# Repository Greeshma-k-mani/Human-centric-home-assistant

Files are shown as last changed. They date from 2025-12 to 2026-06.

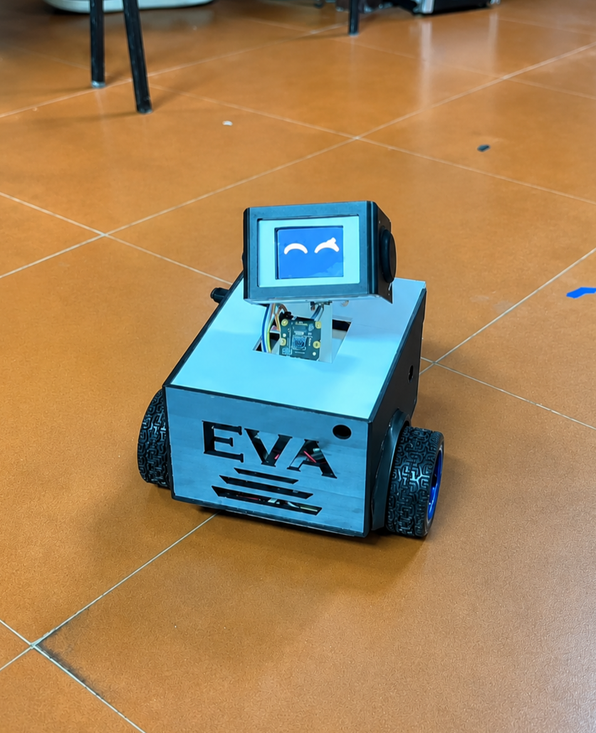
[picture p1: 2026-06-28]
HUMAN_CENTRIC_EMBODIED_HOME_ASSISTANT.png

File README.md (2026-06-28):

# EVA — Human Centered Embodied Home Assistant 🤖

> Voice-activated home assistant robot with face recognition, radar presence detection,
> expressive head movement, and smart home automation.
> 
> 🥇 **First Place — INNOVIX, RISE 2026 | FISAT ECE Department**

---

## 🧠 What is EVA?

EVA is a fully functional human-centric home assistant robot built on **Raspberry Pi 2 + ESP32**,
designed to recognize users, navigate to them, and assist through natural voice interaction.

Unlike conventional voice assistants, EVA physically moves to the user, verifies identity
through face recognition, and responds with expressive animations — making interaction
more natural and personal.

---

## ⚙️ System Architecture

```
┌─────────────────────────────────────────┐
│         RASPBERRY PI 2 MODEL B          │
│  Face Recognition · Voice · Navigation  │
│  Intent Engine · Flask Web UI · Groq AI │
└──────────────┬──────────────────────────┘
               │ HTTP (WiFi)
┌──────────────▼──────────────────────────┐
│              ESP32 WROOM-32             │
│  Motors · Servos · TFT · Radar · Face  │
└──────────────────────────────────────────┘
               │ HTTP (WiFi)
┌──────────────▼──────────────────────────┐
│            ESP8266 NodeMCU              │
│     Garden Relay · Light Control        │
└──────────────────────────────────────────┘
```

---

## 🔧 Features

| Feature | Details |
|---|---|
| 🎙️ Wake Word | Porcupine — "Hey Eva" |
| 👁️ Face Recognition | OpenCV — Haar + LBPH |
| 📡 Presence Detection | LD2410 mmWave Radar |
| 😊 Face Display | ST7735R TFT — 6 bitmap expressions |
| 🤖 3-DoF Head | MG90S servos — Yaw · Pitch · Roll |
| 🚗 Navigation | TB6612FNG + N25 gear motors |
| 🏠 Home Automation | ESP8266 relay — pump + lights |
| 🧠 AI Conversation | Groq LLM (Llama 3) |
| 🌐 Web UI | Flask dashboard — auth + controls |
| 🔌 Custom PCB | KiCad 9.0.5 — full system integration |
| 🖨️ Body | 3D printed enclosure (PLA) |

---

## 🛠️ Hardware

- Raspberry Pi 2 Model B
- ESP32 WROOM-32 DevKit
- ESP8266 NodeMCU
- Pi Camera Module V2 (NoIR)
- ST7735R TFT Display
- HLK-LD24 mmWave Radar
- TB6612FNG Motor Driver
- N25 Metal Gear Motors × 2
- MG90S Servo Motors × 3
- PAM8403 Audio Amplifier
- Custom PCB (KiCad 9.0.5)
- 2S Li-ion Battery (7.4V)

---

## 💻 Software Stack

```python
stack = {
    "Pi"      : ["Python 3", "OpenCV", "Porcupine", "Flask",
                 "edge-TTS", "Google STT", "Groq LLM"],
    "ESP32"   : ["Arduino C++", "WebServer", "SPI", "LEDC PWM"],
    "ESP8266" : ["Arduino C++", "ESP8266WebServer"],
    "PCB"     : ["KiCad 9.0.5"],
    "Body"    : ["Fusion 360", "3D Printing (PLA)"],
}
```

---

## 📬 Contact




---

GitHub: https://github.com/Greeshma-k-mani

LinkedIn: https://www.linkedin.com/in/greeshma-k-mani

<p align="center"><i>Built with curiosity. Powered by embedded silicon. Driven by the need to build things that actually work.</i></p>

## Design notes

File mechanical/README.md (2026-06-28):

## 3DOF Head Mechanical Design

This directory contains the mechanical design files for a 3DOF servo-driven head
used in the early development phase of the interactive home assistant robot.

Degrees of Freedom:
- Yaw (left / right)
- Pitch (up / down)
- Roll (tilt)

Design notes:
- Designed for MG90S micro servos
- Optimized for 3D printing (PLA)
- Intended for expressive motion, not load-bearing use

## File Structure
- Assembly files are located in this directory
- Render images are located in the `renders/` folder

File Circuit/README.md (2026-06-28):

# PCB Design — EVA Human Centered Embodied Home Assistant

Circuit schematic and PCB layout for the EVA project, designed using **KiCad 9.0.5**.

---

## 📋 System Overview

| Controller | Role |
|---|---|
| **Raspberry Pi 2 Model B** | Face recognition, voice interaction, navigation logic, Flask web UI |
| **ESP32 WROOM-32** | Motors, servos, TFT display, radar, HTTP server |
| **ESP8266 NodeMCU** | Garden relay control, WiFi automation |

---

## 🔌 Peripherals

| Component | Interface |
|---|---|
| ST7735R TFT Display | SPI |
| MG90S Servo × 3 (Yaw, Pitch, Roll) | PWM |
| TB6612FNG Motor Driver | PWM + GPIO |
| N25 Gear Motors × 2 | TB6612FNG |
| HLK-LD24 mmWave Radar | UART2 |
| 2-Channel Relay Module | GPIO (ESP8266) |
| PAM8403 Audio Amplifier | GPIO |

---

## ⚡ Power Architecture

- **Source:** 2S Li-ion Battery (7.4V)
- **MINI560:** 5V regulated — Raspberry Pi
- **Mini360:** 3.3V regulated — ESP32, ESP8266, logic
- **LM2590:** 6V regulated — Motors and servos
- **Protection:** 10A fuse + power switch
- **Decoupling:** Bulk and bypass capacitors on all power rails

---

## 📐 PCB Design Status

| Item | Status |
|---|---|
| Schematic | ✅ Completed |
| PCB Layout | ✅ Completed |
| 3D Render | ✅ Completed |
| Fabrication | ✅ Fabricated |
| Testing | ✅ Tested |
| Design Tool | KiCad 9.0.5 |

---

---

## 📝 Design Notes

- Common ground reference across all modules
- Decoupling capacitors placed close to all ICs
- High-current motor and servo rails isolated from logic rails
- Designed for low-voltage, non-safety-critical academic use

---

> This PCB is part of an academic embedded systems project and is not intended for commercial or safety-critical applications.

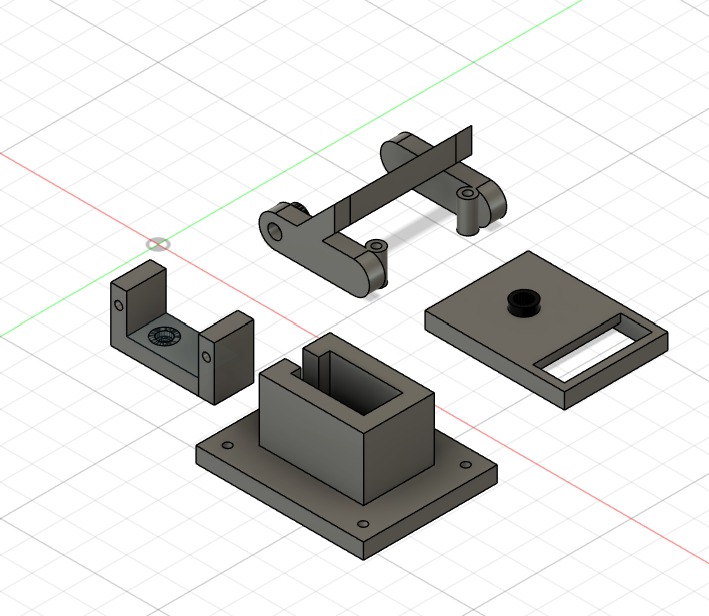
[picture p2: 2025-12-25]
mechanical/renders/exploded view.jpeg

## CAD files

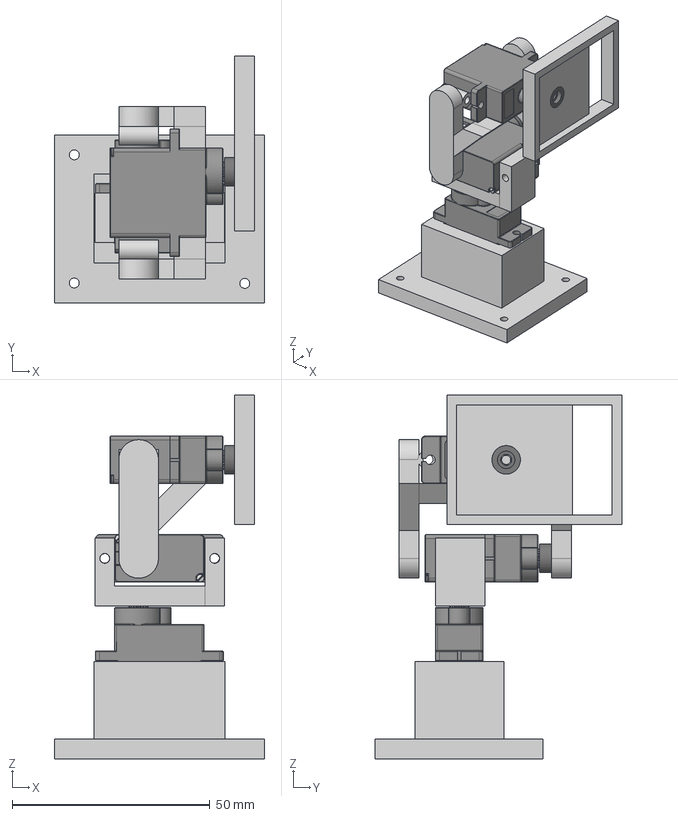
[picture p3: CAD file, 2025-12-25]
mechanical/assembly/head_assembly_v1.step
53.1 x 62.3 x 92.0 mm
Shaft x 3
Horn x 3
Screw x 3

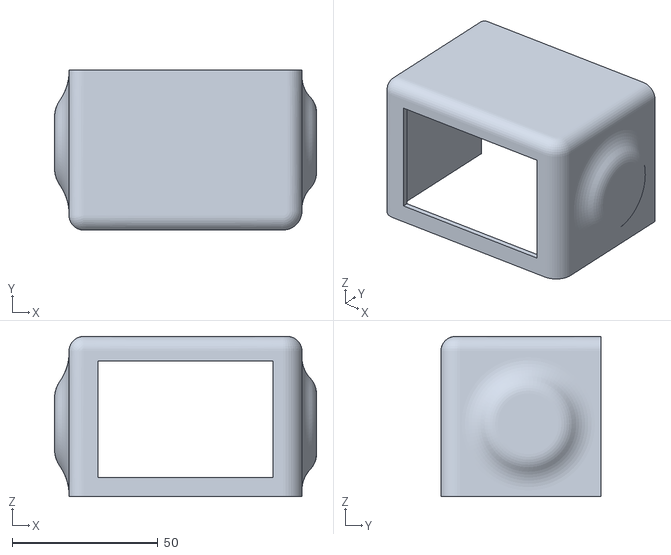
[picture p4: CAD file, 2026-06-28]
mechanical/parts/EVA_HEAD_COVER.stl
90.0 x 55.0 x 55.0

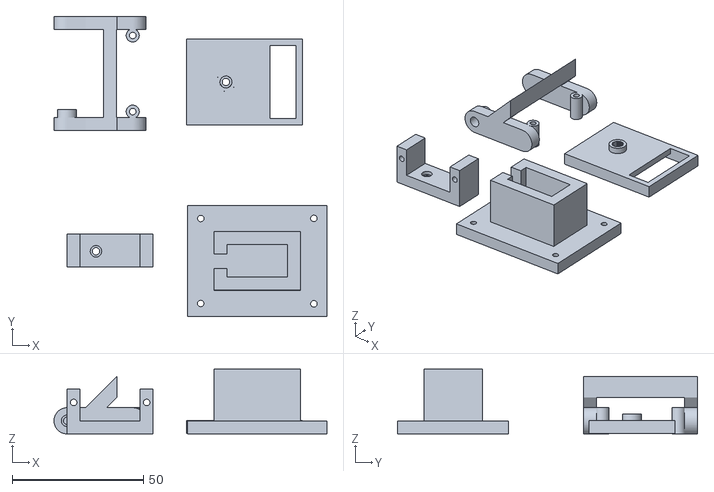
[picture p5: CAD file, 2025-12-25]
mechanical/assembly/exploded_view_v1.stl
104.0 x 114.4 x 24.7

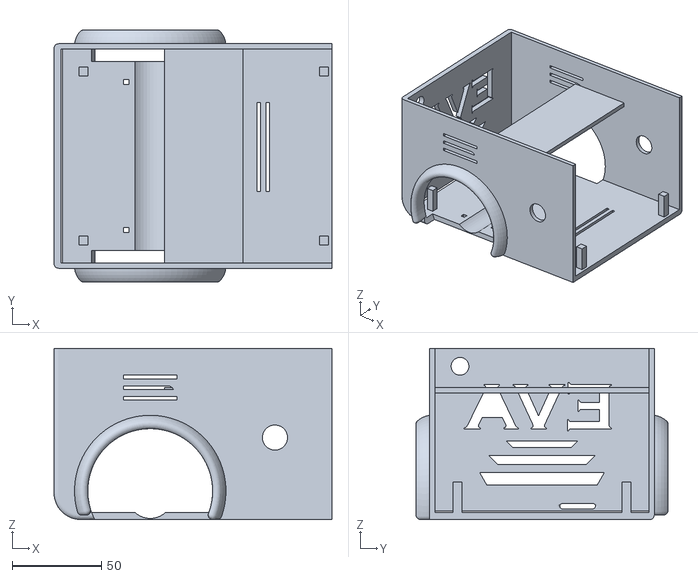
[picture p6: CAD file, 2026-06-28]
mechanical/parts/EVA_BODY.stl
156.0 x 141.4 x 96.0

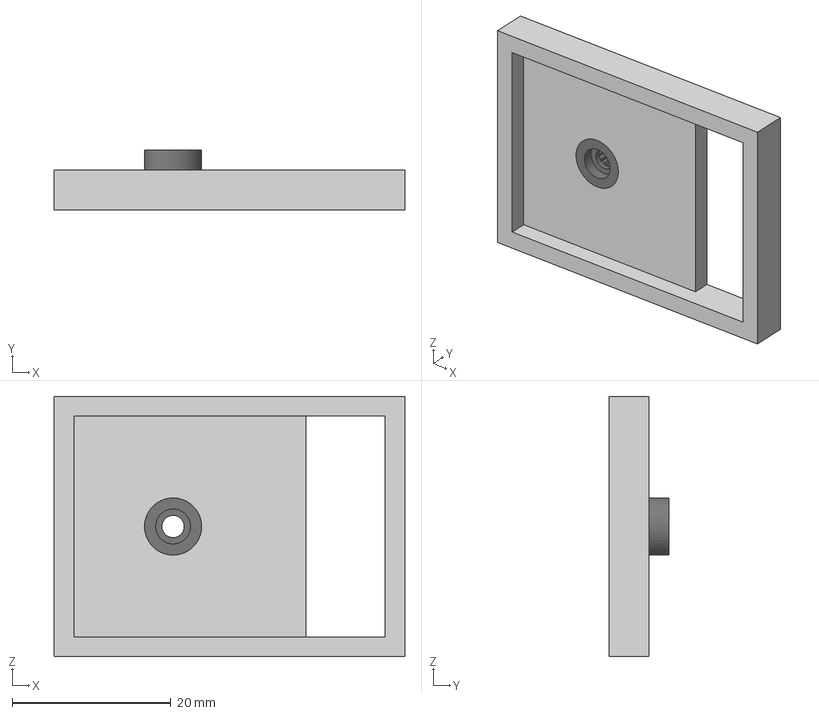
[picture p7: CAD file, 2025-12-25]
mechanical/parts/roll_mount_v1.step
44.2 x 7.50 x 32.8 mm
Shaft
Horn
Screw

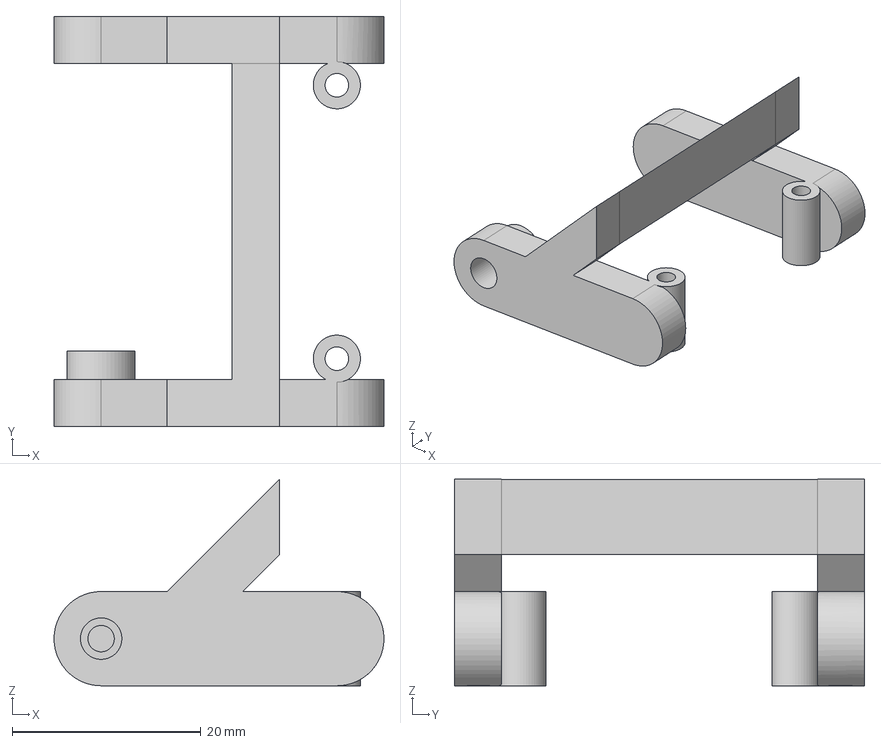
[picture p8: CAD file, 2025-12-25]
mechanical/parts/pitch_mount_v1.step
35.0 x 43.5 x 21.9 mm
Shaft
Horn
Screw

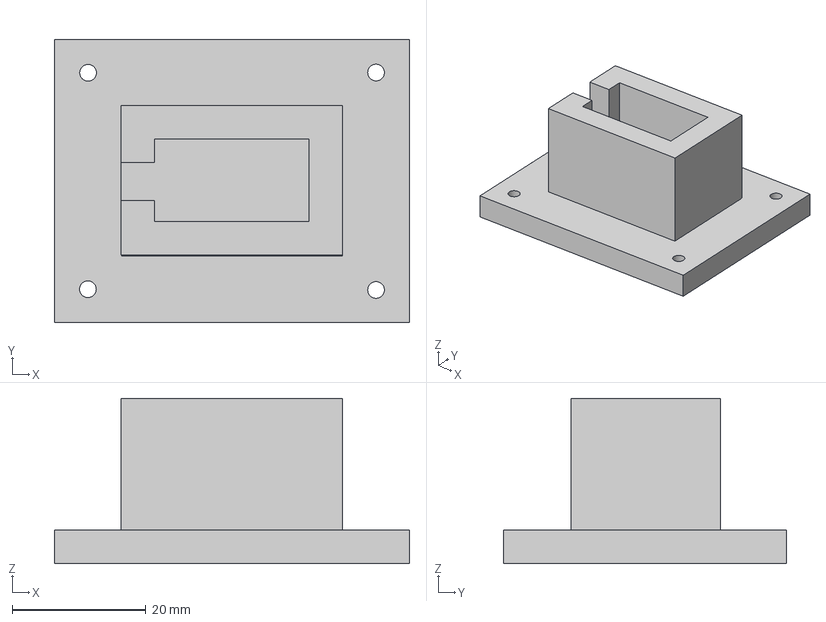
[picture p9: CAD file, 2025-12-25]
mechanical/parts/base_mount_v1.step
53.1 x 42.4 x 24.7 mm

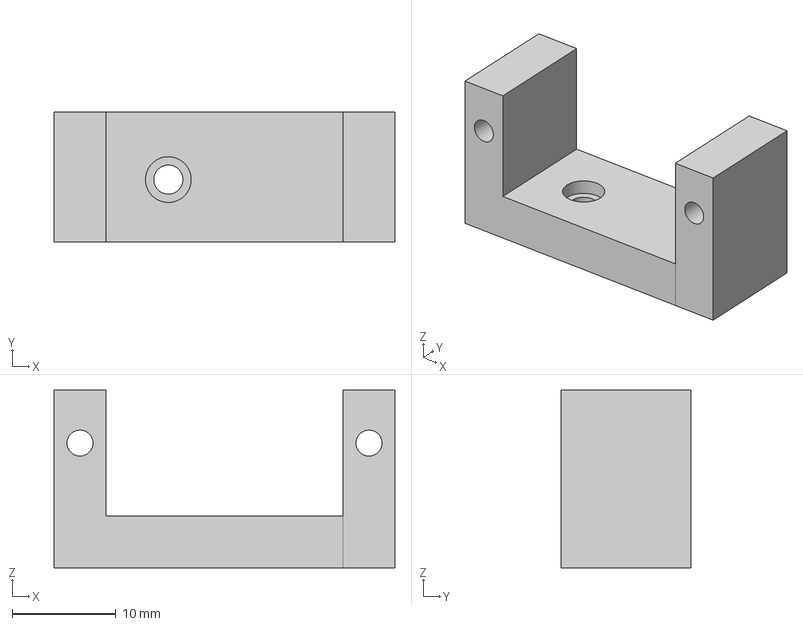
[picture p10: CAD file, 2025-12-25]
mechanical/parts/yaw_mount_v1.step
32.8 x 12.5 x 17.1 mm
Shaft
Horn
Screw

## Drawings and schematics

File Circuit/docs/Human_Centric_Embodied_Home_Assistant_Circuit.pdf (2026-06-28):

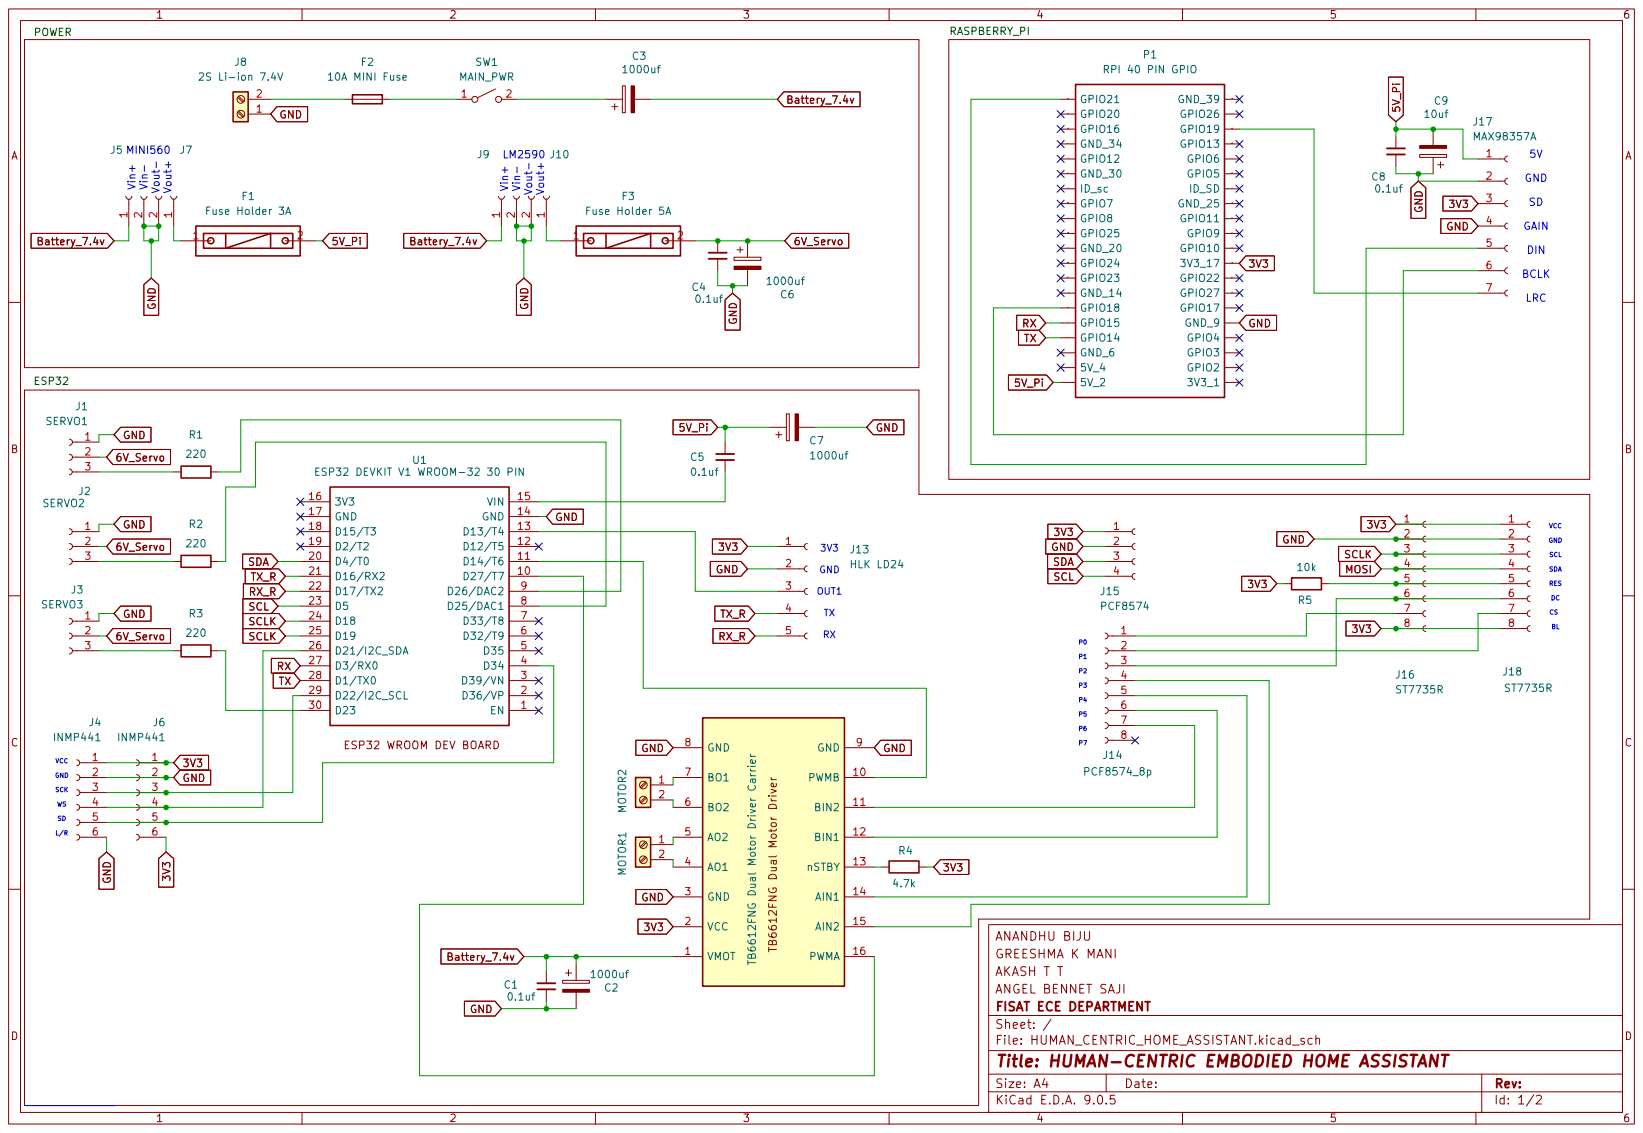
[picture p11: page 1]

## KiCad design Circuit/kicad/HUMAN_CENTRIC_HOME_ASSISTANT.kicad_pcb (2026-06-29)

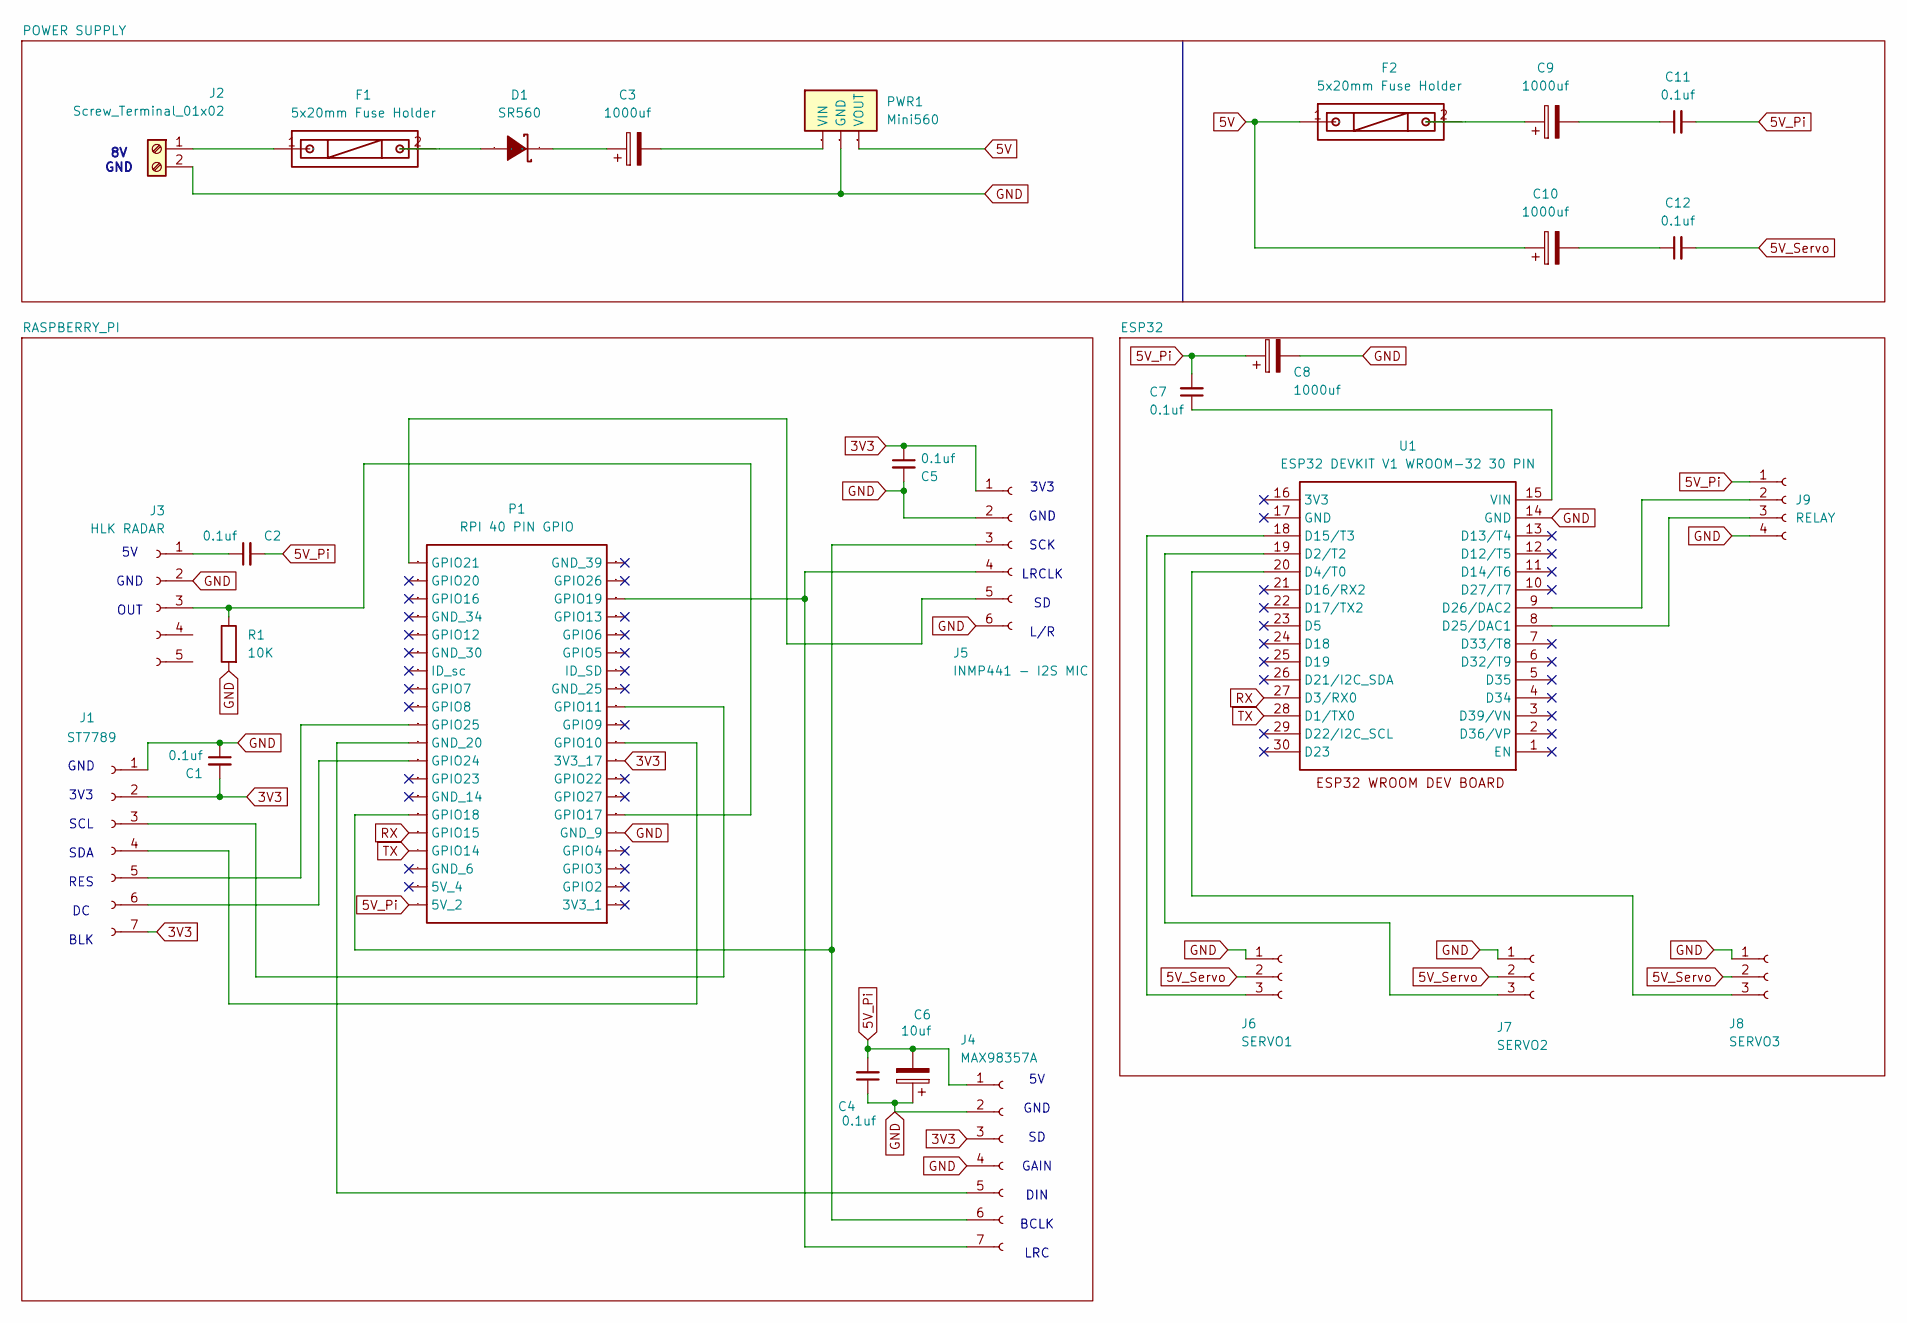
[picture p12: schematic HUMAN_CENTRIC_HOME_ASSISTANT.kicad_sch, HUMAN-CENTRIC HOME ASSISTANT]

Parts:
C1, C2, C4, C5, C7, C11, C12: 0.1uf; C_Disc_D5.0mm_W2.5mm_P5.00mm
C3, C8, C9, C10: 1000uf; CP_Radial_D10.0mm_P5.00mm
C6: 10uf; CP_Radial_D6.3mm_P2.50mm
D1: SR560; SR560 Schottky Barrier Rectifier Diode 5A; Manufacturer Part SR560
F1, F2: 5x20mm Fuse Holder; 5X20-FUSE
J1: ST7789; PINHEADER_1X07_P2.54MM_VERTICAL
J2: Screw_Terminal_01x02; SCREWTERMINAL-5MM-2-DW
J3: HLK RADAR; PINHEADER_1X05_P2.54MM_VERTICAL
J4: MAX98357A; PINHEADER_1X07_P2.54MM_VERTICAL
J5: INMP441 - I2S MIC; CONNECTOR_PINHEADER_2.54MMPINHEADER_1X06_P2.54MM_VERTICAL
J6: SERVO1; CONN-HEADER-STRAIGHT-P2.54MM-1X03
J7: SERVO2; CONN-HEADER-STRAIGHT-P2.54MM-1X03
J8: SERVO3; CONN-HEADER-STRAIGHT-P2.54MM-1X03
J9: RELAY; PINSOCKET_1X04_P2.54MM_VERTICAL
P1: RPI 40 PIN GPIO; 2X20-PIN-HEADER
PWR1: Mini560; MINI560; Manufacturer Part mini560
R1: 10K; R_Axial_DIN0207_L6.3mm_D2.5mm_P7.62mm_Horizontal
U1: ESP32 DEVKIT V1 WROOM-32 30 PIN; ESP32 DEVKIT V1 30 PIN

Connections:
3V3: C1.2, C5.1, J1.2, J1.7, J4.3, J5.1, P1.17 (3V3_17)
5V: C10.1, F2.1, PWR1.VOUT
5V_Pi: C2.2, C4.2, C6.2, C7.2, C8.1, C11.2, J4.1, J9.1, P1.2 (5V_2)
5V_Servo: C12.2, J6.2, J7.2, J8.2
GND: C1.1, C4.1, C5.2, C6.1, C8.2, J1.1, J2.2, J3.2, J4.2, J4.4, J5.2, J5.6, J6.1, J7.1, J8.1, J9.4, P1.9 (GND_9), PWR1.GND, R1.1, U1.14 (GND)
unnamed: C3.2, PWR1.VIN
unnamed: C9.1, F2.2
unnamed: C10.2, C12.1
unnamed: C9.2, C11.1
unnamed: D1.1 (A), F1.2
unnamed: C3.1, D1.2 (K)
unnamed: J1.3, P1.23 (GPIO11)
unnamed: J1.4, P1.19 (GPIO10)
unnamed: J1.5, P1.22 (GPIO25)
unnamed: J1.6, P1.18 (GPIO24)
unnamed: F1.1, J2.1
unnamed: C2.1, J3.1
unnamed: J3.3, P1.11 (GPIO17), R1.2
unnamed: J4.5, P1.20 (GND_20)
unnamed: J4.6, J5.3, P1.12 (GPIO18)
unnamed: J4.7, J5.4, P1.35 (GPIO19)
unnamed: J5.5, P1.40 (GPIO21)
unnamed: J6.3, U1.18 (D15/T3)
unnamed: J7.3, U1.19 (D2/T2)
unnamed: J8.3, U1.20 (D4/T0)
unnamed: J9.2, U1.9 (D26/DAC2)
unnamed: J9.3, U1.8 (D25/DAC1)
unnamed: C7.1, U1.15 (VIN)
RX: P1.10 (GPIO15), U1.27 (D3/RX0)
TX: P1.8 (GPIO14), U1.28 (D1/TX0)

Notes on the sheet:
8V GND
3V3 GND SCK LRCLK SD L/R
GND 3V3 SCL SDA RES DC BLK
5V GND SD GAIN DIN BCLK LRC
5V GND OUT

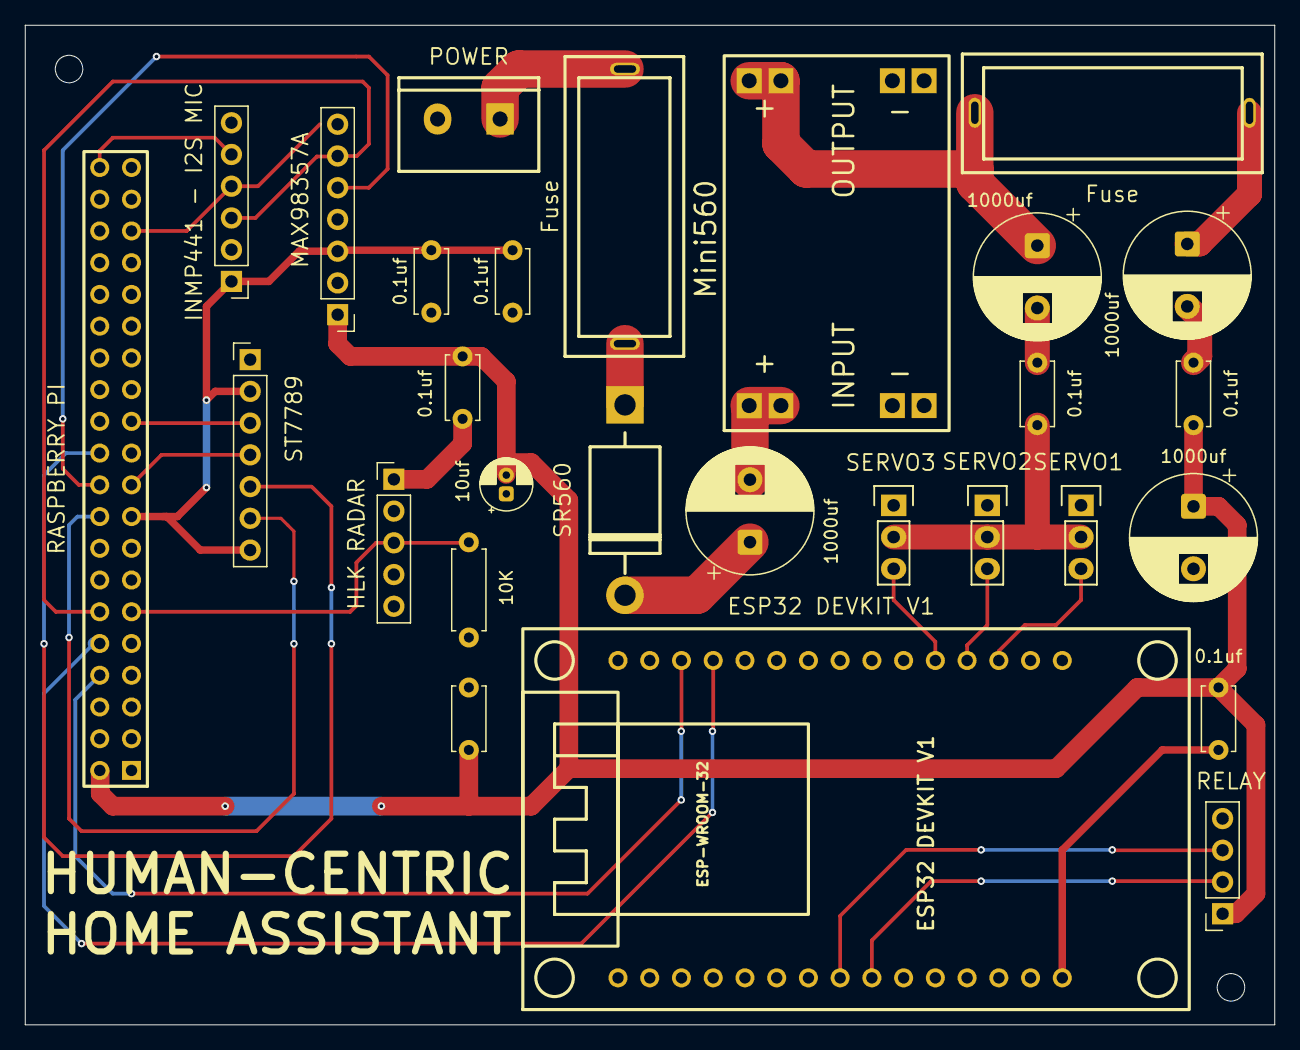
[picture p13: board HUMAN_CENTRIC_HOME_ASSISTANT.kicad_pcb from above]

Board: 2 copper layers, 100.0 x 80.0 mm, 28 parts (0 on the bottom side), 30 nets.

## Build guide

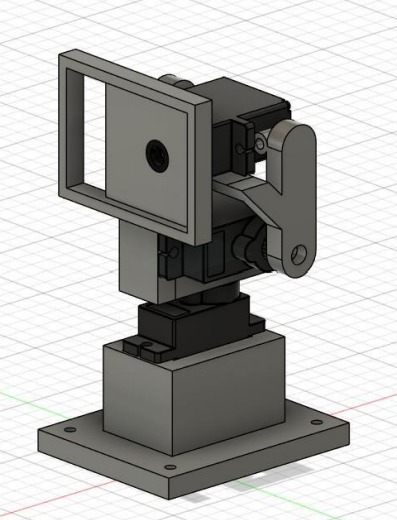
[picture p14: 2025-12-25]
mechanical/renders/assembled view.jpeg

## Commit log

2025-12-25 Revise README with project details and objectives
    Updated project title and added detailed project overview, objectives, system architecture, current status, and tools used.
2025-12-25 Add README for 3 DOF Servo-Based Head Mechanism
    Added detailed documentation for the mechanical design and implementation of a 3-DOF servo-based head mechanism, including design overview, fabrication methods, and current status.
2026-06-29 Update PCB files
    [HUMAN_CENTRIC_HOME_ASSISTANT.kicad_pcb, HUMAN_CENTRIC_HOME_ASSISTANT.kicad_sch]
